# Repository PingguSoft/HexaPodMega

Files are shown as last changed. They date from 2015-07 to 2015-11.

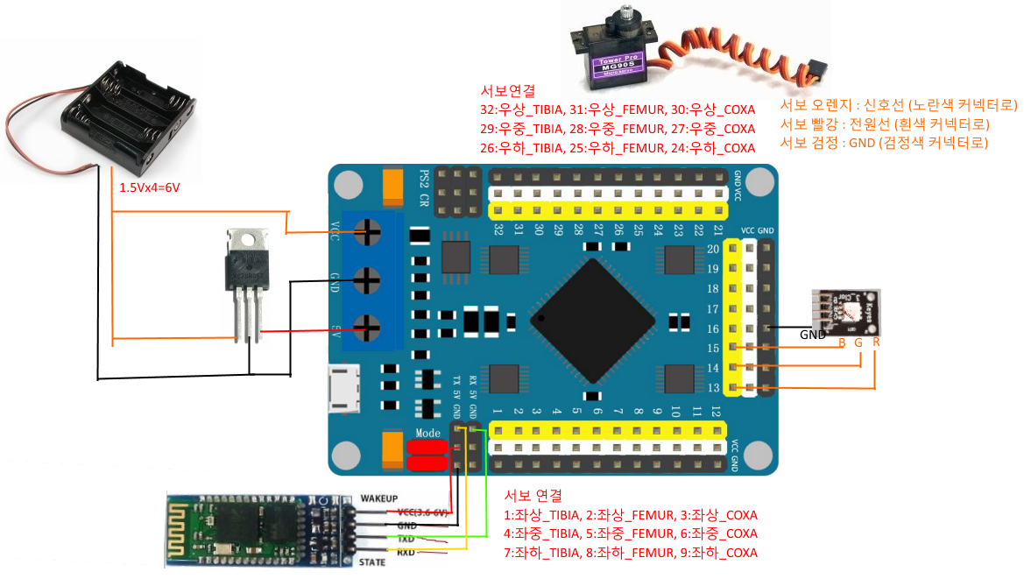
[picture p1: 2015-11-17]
Schematic/ServoController/servo_controller_connection.png

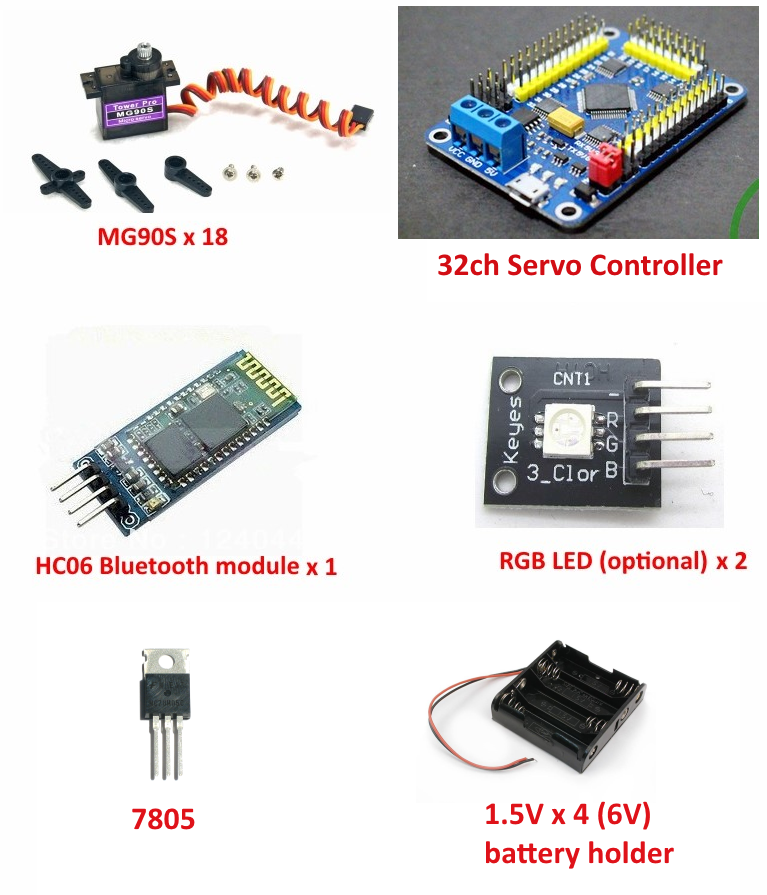
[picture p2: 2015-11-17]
Schematic/ServoController/elec-part2.png

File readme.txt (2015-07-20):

User guide
http://www.lynxmotion.com/images/html/build131.htm
http://www.lynxmotion.com/images/html/build99f.htm
http://www.lynxmotion.com/images/html/build159.htm
http://www.lynxmotion.com/s-6-projects-how-tos.aspx
https://github.com/KurtE/Arduino_Phoenix_Parts
http://learn.trossenrobotics.com/10-interbotix/crawlers/phantomx-hexapod/68-phoenix-code.html

http://www.trossenrobotics.com/
https://code.google.com/p/arbotix/wiki/NukeIntro
http://learn.trossenrobotics.com/10-interbotix/crawlers/phantomx-hexapod/133-phantomx-hexapod-assembly-guide.html

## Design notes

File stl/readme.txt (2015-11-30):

http://www.thingiverse.com/thing:432829
http://www.thingiverse.com/make:130253

Update : modified Phoenix source code added to the files

part needed :
18 mg90s servos
18 623 bearing
1 arduino nano
1 servo controler
1 buzzer
2 led +resistor
1 wireless ps2 controler 
1 rc on-off switch
1 or 2 ubec regulators
diodes.
some siliconed glue to make grip for the foots. (or ninja flex)
many m3 nuts and bolts
and very very little fingers to plug all wire together.
video : https://www.youtube.com/watch?v=Igf-VEXJJVw
sorry for te poor camreman and for the delay on some actions ( i'm trying to remember what all the ps2 button do ;) )
it was made with 123d design.
the code is the kurt's phoenix heavely modified 
Pay attention, in my design all the legs are the same : no left and right design, you must invert rotation by code.

--legs--
epaule_v2 * 6
femur_v2  * 6
tibia-v2  * 6

bottom    * 1
top       * 1
side      * 4

back      * 1  
door      * 1 (bottom door)

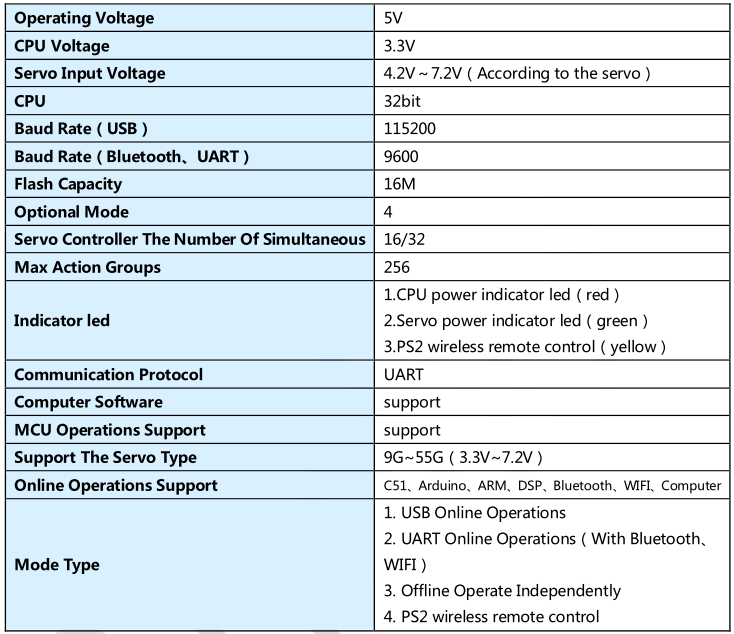
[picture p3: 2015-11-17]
Schematic/ServoController/servo.png

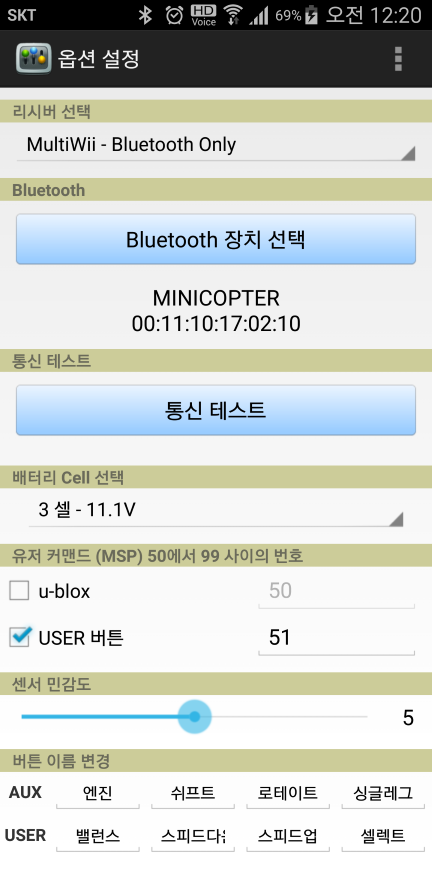
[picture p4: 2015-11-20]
Schematic/ArduinoMega/app1.png

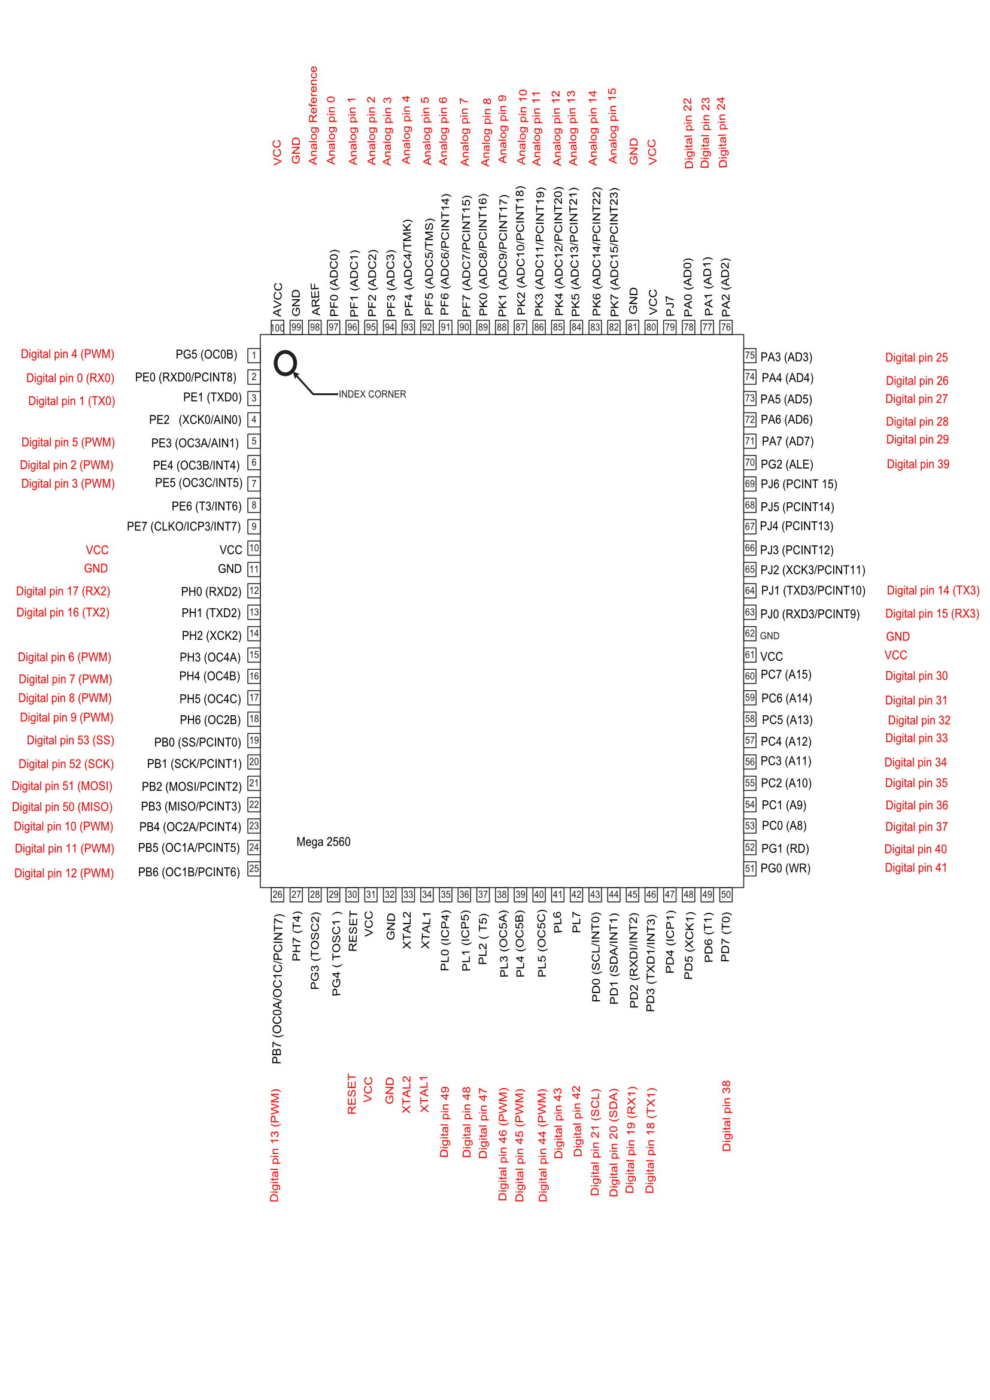
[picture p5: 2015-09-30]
Schematic/ArduinoMega/Pins2560s.png

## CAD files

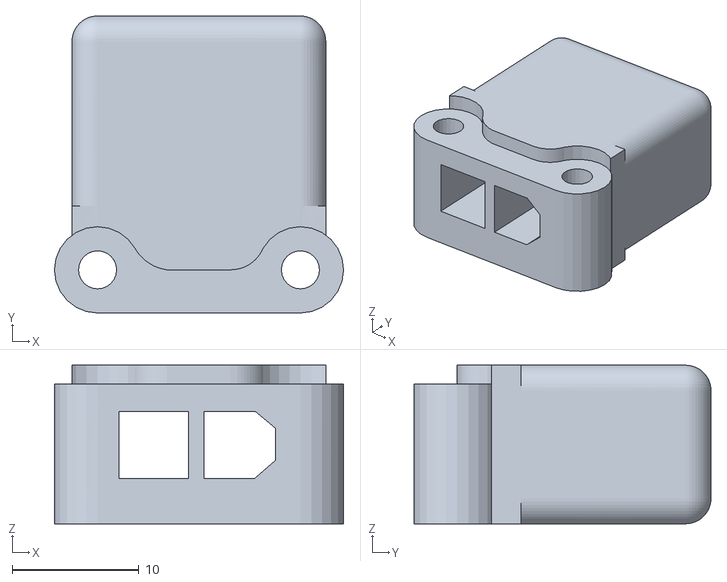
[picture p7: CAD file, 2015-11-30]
stl/BattConnHolder_V2.stl
22.8 x 23.4 x 12.5

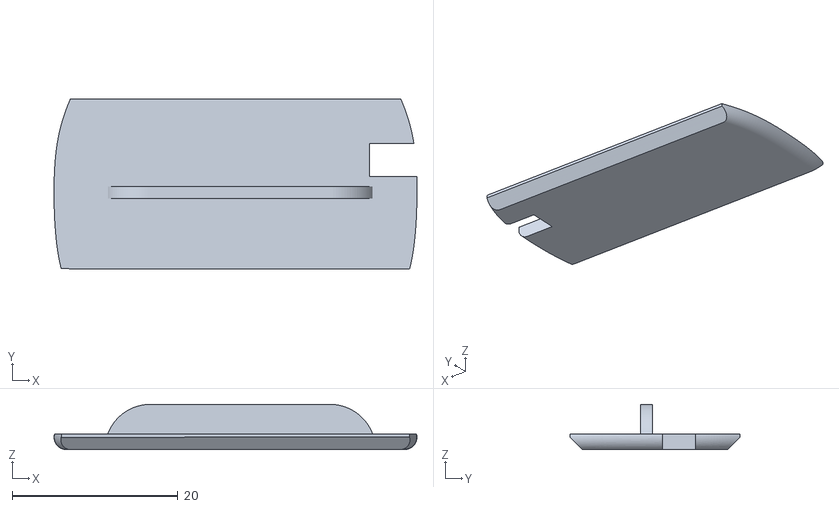
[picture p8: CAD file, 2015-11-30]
stl/updated/head_back.stl
43.9 x 20.6 x 5.47

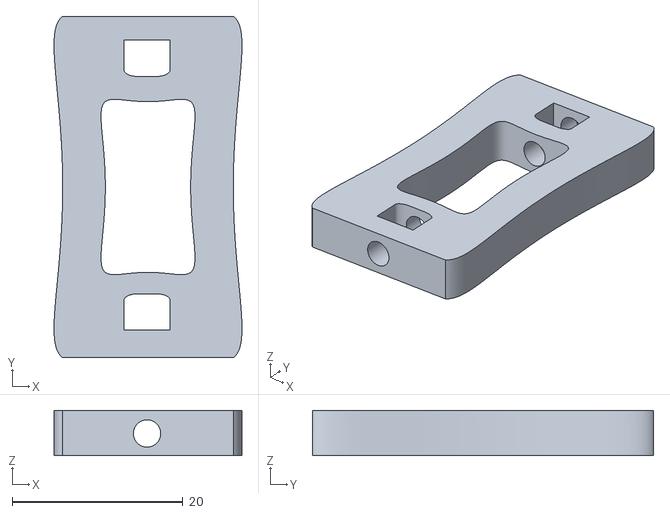
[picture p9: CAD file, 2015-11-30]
stl/hexa_side.stl
22.0 x 40.0 x 5.32

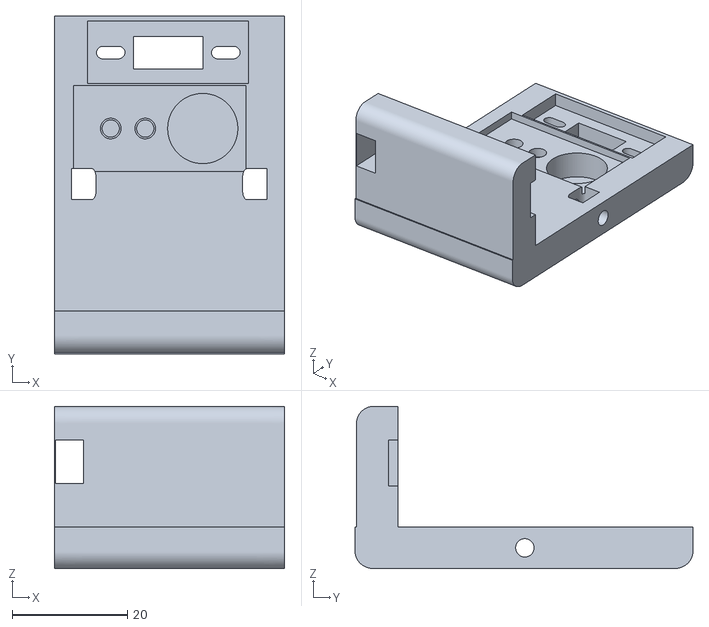
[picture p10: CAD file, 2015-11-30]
stl/hexa_Back.stl
40.0 x 58.8 x 28.2

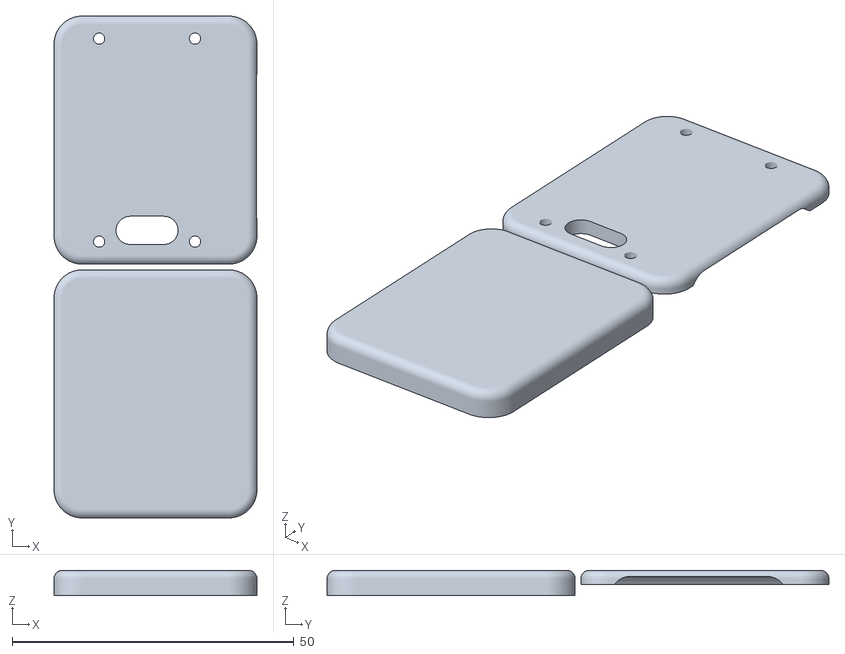
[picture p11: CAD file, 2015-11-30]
stl/ps2_box.stl
36.0 x 89.0 x 4.50

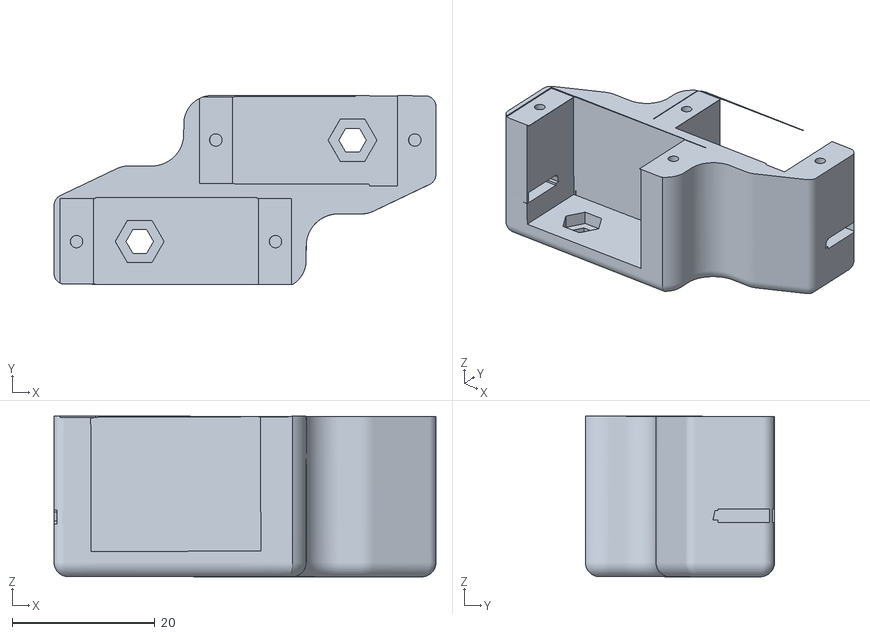
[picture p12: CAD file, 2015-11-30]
stl/femur_v2.stl
53.6 x 26.5 x 22.5

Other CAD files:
stl/hexa_back_xt60.stl

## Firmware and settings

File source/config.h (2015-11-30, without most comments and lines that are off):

#define __CONFIG_H__
#include "common.h"
#if defined(__AVR_ATmega168__) || defined(__AVR_ATmega328P__)
  #define CONFIG_CPU_PROMINI
#elif defined(__AVR_ATmega32U4__) || defined(TEENSY20)
  #define CONFIG_CPU_PROMICRO
#elif defined(__AVR_ATmega1280__) || defined(__AVR_ATmega1281__) || defined(__AVR_ATmega2560__) || defined(__AVR_ATmega2561__)
  #define CONFIG_CPU_MEGA
#endif
#define CONFIG_DOF_PER_LEG      3
#define CONFIG_NUM_LEGS         6
#define CONFIG_TRAVEL_DEAD_ZONE 4
#define CONFIG_ORIGINAL         1
#define CONFIG_NASSPOP_MEGA     2
#define CONFIG_NASSPOP_MINI     3
#define CONFIG_CTRL_TYPE_SERIAL 1
#define CONFIG_CTRL_TYPE_BTCON  2
#define CONFIG_SERVO_SW_PWM     1
#define CONFIG_SERVO_USC        2
#define CONFIG_VBAT_SMOOTH      16
#define CONFIG_VBAT_SCALE       48
#define CONFIG_VBAT_OFFSET      -1   // 0.1v unit
#define CONFIG_VOLT_OFF         111
#define CONFIG_VOLT_ON          115
#define CONFIG_BOARD            CONFIG_NASSPOP_MEGA
#if defined(CONFIG_CPU_MEGA) && !defined(CONFIG_BOARD)
    #error DEFINE CONFIG_BOARD !!!
#elif defined(CONFIG_CPU_PROMINI)
    #define CONFIG_BOARD        CONFIG_NASSPOP_MINI
#endif
#if (CONFIG_BOARD == CONFIG_ORIGINAL)
    #define PIN_ANALOG_VOLT A0
    #define CONFIG_CTRL_SERIAL  Serial
    #define CONFIG_CTRL_BAUD    115200
    #define CONFIG_SERVO        CONFIG_SERVO_SW_PWM
    #define CONFIG_CTRL_TYPE    CONFIG_CTRL_TYPE_BTCON
    #define PIN_STATUS_RED      31
    #define PIN_STATUS_GREEN    30
    #define PIN_STATUS_BLUE     32
    #define PIN_SOUND           37
    #define PIN_RR_COXA         35  //Rear Right leg Hip Horizontal
    #define PIN_RR_FEMUR        36  //Rear Right leg Hip Vertical
    #define PIN_RR_TIBIA        19  //Rear Right leg Knee
    #define PIN_RR_TARS          1  //Tar
    #define PIN_RM_COXA         25  //Middle Right leg Hip Horizontal
    #define PIN_RM_FEMUR        33  //Middle Right leg Hip Vertical
    #define PIN_RM_TIBIA        34  //Middle Right leg Knee
    #define PIN_RM_TARS         1   //Tar
    #define PIN_RF_COXA         22  //Front Right leg Hip Horizontal
    #define PIN_RF_FEMUR        23  //Front Right leg Hip Vertical
    #define PIN_RF_TIBIA        24  //Front Right leg Knee
    #define PIN_RF_TARS         1   //Tar
    #define PIN_LR_COXA         9  //Rear Left leg Hip Horizontal
    #define PIN_LR_FEMUR        10  //Rear Left leg Hip Vertical
    #define PIN_LR_TIBIA        11  //Rear Left leg Knee
    #define PIN_LR_TARS         1  //Tar
    #define PIN_LM_COXA         6  //Middle Left leg Hip Horizontal
    #define PIN_LM_FEMUR        7  //Middle Left leg Hip Vertical
    #define PIN_LM_TIBIA        8  //Middle Left leg Knee
    #define PIN_LM_TARS         1  //Tar = Not working...
    #define PIN_LF_COXA         2  //Front Left leg Hip Horizontal
    #define PIN_LF_FEMUR        3  //Front Left leg Hip Vertical
    #define PIN_LF_TIBIA        5  //Front Left leg Knee
    #define PIN_LF_TARS         1  //Tar
#elif (CONFIG_BOARD == CONFIG_NASSPOP_MEGA)
    #define CONFIG_DBG_SERIAL   Serial
    #define CONFIG_DEBUG_BAUD   115200
    #define CONFIG_CTRL_SERIAL  Serial1
    #define CONFIG_CTRL_BAUD    115200
    #define CONFIG_SERVO        CONFIG_SERVO_SW_PWM
    #define CONFIG_CTRL_TYPE    CONFIG_CTRL_TYPE_BTCON
    #define PIN_STATUS_RED      A7
    #define PIN_STATUS_GREEN    A6
    #define PIN_STATUS_BLUE     A5
    #define PIN_SOUND           A14
    #define PIN_RR_COXA         44  //Rear Right leg Hip Horizontal
    #define PIN_RR_FEMUR        45  //Rear Right leg Hip Vertical
    #define PIN_RR_TIBIA        46  //Rear Right leg Knee
    #define PIN_RR_TARS          1  //Tar
    #define PIN_RM_COXA         35  //Middle Right leg Hip Horizontal
    #define PIN_RM_FEMUR        33  //Middle Right leg Hip Vertical
    #define PIN_RM_TIBIA        36  //Middle Right leg Knee
    #define PIN_RM_TARS          1  //Tar
    #define PIN_RF_COXA         A15 //Front Right leg Hip Horizontal
    #define PIN_RF_FEMUR        32  //Front Right leg Hip Vertical
    #define PIN_RF_TIBIA        34  //Front Right leg Knee
    #define PIN_RF_TARS          1  //Tar
    #define PIN_LR_COXA         9  //Rear Left leg Hip Horizontal
    #define PIN_LR_FEMUR        10  //Rear Left leg Hip Vertical
    #define PIN_LR_TIBIA        11  //Rear Left leg Knee
    #define PIN_LR_TARS         1  //Tar
    #define PIN_LM_COXA         6  //Middle Left leg Hip Horizontal
    #define PIN_LM_FEMUR        7  //Middle Left leg Hip Vertical
    #define PIN_LM_TIBIA        8  //Middle Left leg Knee
    #define PIN_LM_TARS         1  //Tar = Not working...
    #define PIN_LF_COXA         2  //Front Left leg Hip Horizontal
    #define PIN_LF_FEMUR        3  //Front Left leg Hip Vertical
    #define PIN_LF_TIBIA        5  //Front Left leg Knee
    #define PIN_LF_TARS         1  //Tar
#elif (CONFIG_BOARD == CONFIG_NASSPOP_MINI)
    #define CONFIG_SERVO            CONFIG_SERVO_USC
    #define CONFIG_SERVO_MARGIN     200
    #define CONFIG_SERVO_USC_TX     12
    #define CONFIG_SERVO_USC_RX     11
    #define CONFIG_SERVO_USC_BAUD   9600
    #ifdef CONFIG_DBG_SERIAL
        #define CONFIG_CTRL_SERIAL      Serial
        #define CONFIG_CTRL_BAUD        115200
        #define CONFIG_CTRL_TYPE        CONFIG_CTRL_TYPE_SERIAL
    #else
        #define CONFIG_CTRL_SERIAL      Serial
        #define CONFIG_CTRL_BAUD        115200
        #define CONFIG_CTRL_TYPE        CONFIG_CTRL_TYPE_BTCON
    #endif
    #if !defined(CONFIG_SERVO_USC_TX) && (CONFIG_SERVO_USC_BAUD != CONFIG_CTRL_BAUD)
        #error SHARED UART BAUD IS NOT SAME !!!
    #endif
    #define PIN_STATUS_RED       6
    #define PIN_STATUS_GREEN     3
    #define PIN_STATUS_BLUE      5
    #define PIN_SOUND            2
    #define PIN_RR_COXA         24  //Rear Right leg Hip Horizontal
    #define PIN_RR_FEMUR        25  //Rear Right leg Hip Vertical
    #define PIN_RR_TIBIA        26  //Rear Right leg Knee
    #define PIN_RR_TARS          0  //Tar
    #define PIN_RM_COXA         27  //Middle Right leg Hip Horizontal
    #define PIN_RM_FEMUR        28  //Middle Right leg Hip Vertical
    #define PIN_RM_TIBIA        29  //Middle Right leg Knee
    #define PIN_RM_TARS          0  //Tar
    #define PIN_RF_COXA         30 //Front Right leg Hip Horizontal
    #define PIN_RF_FEMUR        31  //Front Right leg Hip Vertical
    #define PIN_RF_TIBIA        32  //Front Right leg Knee
    #define PIN_RF_TARS          0  //Tar
    #define PIN_LR_COXA         9  //Rear Left leg Hip Horizontal
    #define PIN_LR_FEMUR        8  //Rear Left leg Hip Vertical
    #define PIN_LR_TIBIA        7  //Rear Left leg Knee
    #define PIN_LR_TARS         0  //Tar
    #define PIN_LM_COXA         6  //Middle Left leg Hip Horizontal
    #define PIN_LM_FEMUR        5  //Middle Left leg Hip Vertical
    #define PIN_LM_TIBIA        4  //Middle Left leg Knee
    #define PIN_LM_TARS         0  //Tar = Not working...
    #define PIN_LF_COXA         3  //Front Left leg Hip Horizontal
    #define PIN_LF_FEMUR        2  //Front Left leg Hip Vertical
    #define PIN_LF_TIBIA        1  //Front Left leg Knee
    #define PIN_LF_TARS         0  //Tar
#endif
#if  (CONFIG_SERVO == CONFIG_SERVO_USC)
    #define CONFIG_SERVO_MARGIN 200
#else
    #define CONFIG_SERVO_MARGIN 0
#endif
#define COXA_MIN_ANG    -800
#define COXA_MAX_ANG     800
#define FEMUR_MIN_ANG   -800
#define FEMUR_MAX_ANG    800
#define TIBIA_MIN_ANG   -800
#define TIBIA_MAX_ANG    800
#define cRRCoxaMin1	    COXA_MIN_ANG	//Mechanical limits of the Right Rear Leg, decimals = 1
#define cRRCoxaMax1	    COXA_MAX_ANG
#define cRRFemurMin1	FEMUR_MIN_ANG
#define cRRFemurMax1	FEMUR_MAX_ANG
#define cRRTibiaMin1	TIBIA_MIN_ANG
#define cRRTibiaMax1	TIBIA_MAX_ANG
#define cRMCoxaMin1	    COXA_MIN_ANG	//Mechanical limits of the Right Middle Leg, decimals = 1
#define cRMCoxaMax1	    COXA_MAX_ANG
#define cRMFemurMin1	FEMUR_MIN_ANG
#define cRMFemurMax1	FEMUR_MAX_ANG
#define cRMTibiaMin1	TIBIA_MIN_ANG
#define cRMTibiaMax1	TIBIA_MAX_ANG
#define cRFCoxaMin1	    COXA_MIN_ANG	//Mechanical limits of the Right Front Leg, decimals = 1
#define cRFCoxaMax1	    COXA_MAX_ANG
#define cRFFemurMin1	FEMUR_MIN_ANG
#define cRFFemurMax1	FEMUR_MAX_ANG
#define cRFTibiaMin1	TIBIA_MIN_ANG
#define cRFTibiaMax1	TIBIA_MAX_ANG
#define cLRCoxaMin1	    COXA_MIN_ANG	//Mechanical limits of the Left Rear Leg, decimals = 1
#define cLRCoxaMax1	    COXA_MAX_ANG
#define cLRFemurMin1	FEMUR_MIN_ANG
#define cLRFemurMax1	FEMUR_MAX_ANG
#define cLRTibiaMin1	TIBIA_MIN_ANG
#define cLRTibiaMax1	TIBIA_MAX_ANG
#define cLMCoxaMin1	    COXA_MIN_ANG	//Mechanical limits of the Left Middle Leg, decimals = 1
#define cLMCoxaMax1	    COXA_MAX_ANG
#define cLMFemurMin1	FEMUR_MIN_ANG
#define cLMFemurMax1	FEMUR_MAX_ANG
#define cLMTibiaMin1	TIBIA_MIN_ANG
#define cLMTibiaMax1	TIBIA_MAX_ANG
#define cLFCoxaMin1	    COXA_MIN_ANG	//Mechanical limits of the Left Front Leg, decimals = 1
#define cLFCoxaMax1	    COXA_MAX_ANG
#define cLFFemurMin1	FEMUR_MIN_ANG
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

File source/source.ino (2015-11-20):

//=============================================================================
//Project Lynxmotion Phoenix
//Description: Phoenix software
//Software version: V2.0
//Date: 29-10-2009
//Programmer: Jeroen Janssen [aka Xan]
//         Kurt Eckhardt(KurtE) converted to C and Arduino
//   KÃ¥re Halvorsen aka Zenta - Makes everything work correctly!
//
// This version of the Phoenix code was ported over to the Arduino Environement
// and is specifically configured for the Lynxmotion BotBoarduino
//
// Date : 12-07-2015
// Programmer : PingguSoft (pinggusoft@gmail.com)
//              Code rework for smartphone control and readability
//              Android App : BTCon4Drone
//               https://play.google.com/store/apps/details?id=com.pinggusoft.btcon
//=============================================================================

#if defined(__AVR_ATmega1280__) || defined(__AVR_ATmega1281__) || defined(__AVR_ATmega2560__) || defined(__AVR_ATmega2561__)
    #define SERIAL_RX_BUFFER_SIZE 256
    #define SERIAL_TX_BUFFER_SIZE 256
#endif

#define DEFINE_HEX_GLOBALS
#if ARDUINO > 99
#include <Arduino.h>
#endif
#include <Wire.h>
#include <EEPROM.h>
#include <SoftwareSerial.h>

#include "common.h"
#include "ServoEx.h"
#include "config.h"
#include "PhoenixCore.h"
#include "PhoenixInput.h"
#include "PhoenixInputSerial.h"
#include "PhoenixInputBTCon.h"
#include "PhoenixServo.h"
#include "PhoenixServoSW.h"
#include "PhoenixServoUSC.h"

enum {
    MODE_WALK = 0,
    MODE_TRANSLATE,
    MODE_ROTATE,
    MODE_SINGLE_LEG
};

PhoenixCore  *core;
PhoenixInput *input;
CTRL_STATE   ctrlState;

u8        mColor;
s16       mBodyYOffset;
u16       mErrorCnt;
s16       mBodyYShift;
u8        mModeControl;
bool      mBoolDoubleHeight;
bool      mBoolDblTravel;
bool      mBoolWalkMode2;



int freeRam() {
    extern int __heap_start, *__brkval;
    int v;
    return (int) &v - (__brkval == 0 ? (int) &__heap_start : (int) __brkval);
}


#if (CONFIG_CTRL_TYPE == CONFIG_CTRL_TYPE_BTCON)
u8 scale = 30;
s8 inputCallback(u8 cmd, u8 *data, u8 size, u8 *res)
{
    s8 ret = -1;

    switch (cmd) {
        case PhoenixInputBTCon::MSP_ANALOG:
            if (core) {
                u8 *ptr = (u8*)res;

                *ptr = core->getBattLevel(scale);
                *(ptr + 3) = core->getBattLevel();
                ret = 7;
            }
            break;

        case PhoenixInputBTCon::MSP_SET_MISC:
            scale = *(data + 18);
            ret = 0;
            break;
    }
    return ret;
}
#endif

enum {
    COLOR_BLACK  = 0,
    COLOR_RED    = 1,
    COLOR_GREEN  = 2,
    COLOR_YELLOW = 3,
    COLOR_BLUE   = 4,
    COLOR_PURPLE = 5,
    COLOR_CYAN   = 6,
    COLOR_WHITE  = 7
};

void showLED(u8 color)
{
    //printf(F("COLOR : %d\n"), color);
    digitalWrite(PIN_STATUS_RED,   color & 0x01);
    digitalWrite(PIN_STATUS_GREEN, color & 0x02);
    digitalWrite(PIN_STATUS_BLUE,  color & 0x04);
}

void setup()
{
    pinMode(PIN_STATUS_RED,   OUTPUT);
    pinMode(PIN_STATUS_GREEN, OUTPUT);
    pinMode(PIN_STATUS_BLUE,  OUTPUT);
    pinMode(PIN_SOUND, OUTPUT);

    mColor       = 0;
    mBodyYOffset = 0;
    mBodyYShift  = 0;
    mErrorCnt    = 0;

    mModeControl      = MODE_WALK;
    mBoolDoubleHeight = FALSE;
    mBoolDblTravel    = FALSE;
    mBoolWalkMode2    = FALSE;

#ifdef CONFIG_DBG_SERIAL
    CONFIG_DBG_SERIAL.begin(CONFIG_DEBUG_BAUD);
#endif


#if (CONFIG_CTRL_TYPE == CONFIG_CTRL_TYPE_SERIAL)
    input = new PhoenixInputSerial();
	input->init(NULL);

#elif (CONFIG_CTRL_TYPE == CONFIG_CTRL_TYPE_BTCON)
    CONFIG_CTRL_SERIAL.begin(CONFIG_CTRL_BAUD);
    input = new PhoenixInputBTCon(&CONFIG_CTRL_SERIAL);
	input->init(inputCallback);

#else
    #error No Controller !!
#endif


    PhoenixServo    *servo;
#if (CONFIG_SERVO == CONFIG_SERVO_SW_PWM)
    servo = new PhoenixServoSW();

#elif (CONFIG_SERVO == CONFIG_SERVO_USC)
    #if (CONFIG_BOARD == CONFIG_NASSPOP_MINI) && defined(CONFIG_SERVO_USC_TX)
        servo = new PhoenixServoUSC();
    #else
        servo = new PhoenixServoUSC(&CONFIG_CTRL_SERIAL);
    #endif

#endif

    core = new PhoenixCore(servo, &ctrlState);
	core->init();

    printf(F("FREE RAM : %d\n"), freeRam());
}

#define BUTTON_PRESSED(stat, mask) (stat & (mask))

void turnOff(void)
{
    mBodyYOffset = 0;
    mBodyYShift  = 0;
    core->initCtrl();
    Utils::sound(400, 0, 0, 100, 300);
    printf(F("OFF\n"));
}

void loop()
{
    u32  dwButton;
    u8   lx, ly, rx, ry;
    u8   ret;
    bool fAdjustLegPositions = FALSE;

	dwButton = input->get(&lx, &ly, &rx, &ry);

    if (!dwButton)
        goto loop_exit;

    if (BUTTON_PRESSED(dwButton, INPUT_TOGGLE_ON_OFF)) {
    	if (ctrlState.fHexOn) {
            turnOff();
            mColor = 0;
        } else {
            ctrlState.fHexOn = TRUE;
            printf(F("ON\n"));
            Utils::sound(200, 200, 0, 100, 300);
        }
        fAdjustLegPositions = TRUE;
    }

    if (!ctrlState.fHexOn)
        goto loop_exit;

    // Switch between Walk method 1 && Walk method 2
    if (BUTTON_PRESSED(dwButton, INPUT_TOGGLE_WALK)) { // R3 Button Test
        Utils::sound(100, 100, 100, 50, 300);
        mBoolWalkMode2 = !mBoolWalkMode2;
    }

    if (BUTTON_PRESSED(dwButton, INPUT_TOGGLE_SHIFT)) {
        Utils::sound(100, 0, 0, 50, 300);
        if (mModeControl != MODE_TRANSLATE )
            mModeControl = MODE_TRANSLATE;
        else
            mModeControl = MODE_WALK;
        printf(F("MODE:%d\n"), mModeControl);
    }

    if (BUTTON_PRESSED(dwButton, INPUT_TOGGLE_ROTATE)) {
        Utils::sound(300, 0, 0, 50, 300);
        if (mModeControl != MODE_ROTATE)
            mModeControl = MODE_ROTATE;
        else
            mModeControl = MODE_WALK;
        printf(F("MODE:%d\n"), mModeControl);
    }

    if (BUTTON_PRESSED(dwButton, INPUT_TOGGLE_SINGLE_LEG)) {
        if (abs(ctrlState.c3dTravelLen.x) < CONFIG_TRAVEL_DEAD_ZONE && abs(ctrlState.c3dTravelLen.z) < CONFIG_TRAVEL_DEAD_ZONE &&
            abs(ctrlState.c3dTravelLen.y * 2) < CONFIG_TRAVEL_DEAD_ZONE )   {
            Utils::sound(300, 0, 0, 50, 300);

            if (mModeControl != MODE_SINGLE_LEG) {
                mModeControl = MODE_SINGLE_LEG;

            if (ctrlState.bSingleLegCurSel == 255)
                ctrlState.bSingleLegCurSel = PhoenixCore::IDX_RF;
            } else {
                mModeControl = MODE_WALK;
                ctrlState.bSingleLegCurSel = 255;
            }
        }
        printf(F("MODE:%d\n"), mModeControl);
    }

    if (BUTTON_PRESSED(dwButton, INPUT_TOGGLE_BALANCE)) {
        ctrlState.fBalanceMode = !ctrlState.fBalanceMode;
        if (ctrlState.fBalanceMode) {
            Utils::sound(30, 30, 0, 50, 300);
        } else {
            Utils::sound(300, 0, 0, 50, 300);
        }
    }

    if (BUTTON_PRESSED(dwButton, INPUT_TOGGLE_BODY_HEIGHT)) {
        if (mBodyYOffset > 0)
            mBodyYOffset = 0;
        else
            mBodyYOffset = 35;
        fAdjustLegPositions = TRUE;
    }

    if (input->getBodyHeight() & INPUT_HEIGHT_SUPPORTED) {
        mBodyYOffset = input->getBodyHeight() & INPUT_HEIGHT_MASK;
        if (mBodyYOffset > MAX_BODY_Y)
                mBodyYOffset = MAX_BODY_Y;
        fAdjustLegPositions = TRUE;
    } else {
        if (BUTTON_PRESSED(dwButton, INPUT_BODY_UP)) {
            mBodyYOffset += 10;
            if (mBodyYOffset > MAX_BODY_Y)
                mBodyYOffset = MAX_BODY_Y;
            fAdjustLegPositions = TRUE;
        }

        if (BUTTON_PRESSED(dwButton, INPUT_BODY_DOWN) && mBodyYOffset) {
            if (mBodyYOffset > 10)
                mBodyYOffset -= 10;
            else
                mBodyYOffset = 0;
            fAdjustLegPositions = TRUE;
        }
    }

    if (BUTTON_PRESSED(dwButton, INPUT_SPEED_UP)) {
        if (ctrlState.wSpeedControl > 0) {
            ctrlState.wSpeedControl = ctrlState.wSpeedControl - 50;
            Utils::sound(300, 0, 0, 50, 300);
        }
    }

    if (BUTTON_PRESSED(dwButton, INPUT_SPEED_DOWN)) {
        if (ctrlState.wSpeedControl < 2000 ) {
            ctrlState.wSpeedControl = ctrlState.wSpeedControl + 50;
            Utils::sound(300, 0, 0, 50, 300);
        }
    }

    if (mModeControl == MODE_WALK) {
        //Switch gaits
        if (BUTTON_PRESSED(dwButton, INPUT_OPT_SEL)) {
            printf(F("x:%d, y:%d, z:%d\n"), ctrlState.c3dTravelLen.x, ctrlState.c3dTravelLen.y, ctrlState.c3dTravelLen.z);
            if (abs(ctrlState.c3dTravelLen.x) < CONFIG_TRAVEL_DEAD_ZONE &&
                abs(ctrlState.c3dTravelLen.z) < CONFIG_TRAVEL_DEAD_ZONE &&
                abs(ctrlState.c3dTravelLen.y*2) < CONFIG_TRAVEL_DEAD_ZONE) {
                ctrlState.bGaitType = ctrlState.bGaitType + 1;    // Go to the next gait...
                if (ctrlState.bGaitType < NUM_GAITS) {            // Make sure we did not exceed number of gaits...
                    Utils::sound(300, 0, 0, 50, 300);
                } else {
                    Utils::sound(100, 100, 0, 50, 300);
                    ctrlState.bGaitType = 0;
                }
                core->selectGait(ctrlState.bGaitType);
                printf(F("GAIT:%d\n"), ctrlState.bGaitType);
            } else {
                printf(F("GAIT can not be changed:%d\n"), ctrlState.bGaitType);
            }
        }

        // Double leg lift height
        if (BUTTON_PRESSED(dwButton, INPUT_OPT_R1)) {
            Utils::sound(300, 0, 0, 50, 300);
            mBoolDoubleHeight = !mBoolDoubleHeight;
            if (mBoolDoubleHeight)
                ctrlState.sLegLiftHeight = 80;
            else
                ctrlState.sLegLiftHeight = 50;
        }

        // Double Travel Length
        if (BUTTON_PRESSED(dwButton, INPUT_OPT_R2)) {
            Utils::sound(300, 0, 0, 50, 300);
            mBoolDblTravel = !mBoolDblTravel;
        }

        if (mBoolWalkMode2)
            ctrlState.c3dTravelLen.z = (ry - 128); //Right Stick Up/Down
        else {
            ctrlState.c3dTravelLen.x = -(lx - 128);
            ctrlState.c3dTravelLen.z = (ly - 128);
        }

        if (!mBoolDblTravel) {
            ctrlState.c3dTravelLen.x = ctrlState.c3dTravelLen.x / 2;
            ctrlState.c3dTravelLen.z = ctrlState.c3dTravelLen.z / 2;
        }

        ctrlState.c3dTravelLen.y = -(rx - 128)/4; //Right Stick Left/Right
    }

    if (ctrlState.fHexOn)
        mColor = 1 + mModeControl + (mBoolDblTravel ? 4 : 0);

    //[Translate functions]
    mBodyYShift = 0;
    if (mModeControl == MODE_TRANSLATE) {
        ctrlState.c3dBodyPos.x = (ly - 128)/2;
        ctrlState.c3dBodyPos.z = -(ly - 128)/3;
        ctrlState.c3dBodyRot.y = (rx - 128)*2;
        mBodyYShift = (-(ry - 128)/2);
    } else if (mModeControl == MODE_ROTATE) {
        ctrlState.c3dBodyRot.x = (ly - 128);
        ctrlState.c3dBodyRot.y = (rx - 128)*2;
        ctrlState.c3dBodyRot.z = (lx - 128);
        mBodyYShift = (-(ry - 128)/2);
    } else if (mModeControl == MODE_SINGLE_LEG) {
        if (BUTTON_PRESSED(dwButton, INPUT_OPT_SEL)) { // Select Button Test
            Utils::sound(300, 0, 0, 50, 300);
            if (ctrlState.bSingleLegCurSel < 5)
                ctrlState.bSingleLegCurSel = ctrlState.bSingleLegCurSel + 1;
            else
                ctrlState.bSingleLegCurSel = 0;
        }
        ctrlState.c3dSingleLeg.x = (lx - 128) / 2;     // Left Stick Right/Left
        ctrlState.c3dSingleLeg.y = (ry - 128) / 10;    // Right Stick Up/Down
        ctrlState.c3dSingleLeg.z = (ly - 128) / 2;     // Left Stick Up/Down

        // Hold single leg in place
        if (BUTTON_PRESSED(dwButton, INPUT_OPT_R2)) {
            Utils::sound(300, 0, 0, 50, 300);
            ctrlState.fSingleLegHold = !ctrlState.fSingleLegHold;
        }
    }

    ctrlState.bInputTimeDelay = 128 - max( max(abs(lx - 128), abs(ly - 128)),
                                             abs(rx - 128));
    ctrlState.c3dBodyPos.y = min(max(mBodyYOffset + mBodyYShift,  0), MAX_BODY_Y);

loop_exit:
    if (fAdjustLegPositions)
        core->adjustLegPosToBodyHeight();

    showLED(mColor);

    ret = core->loop();
#if 0
    if (ctrlState.fHexOn && (ret & PhoenixCore::STATUS_BATT_FAIL)) {
        turnOff();
        ctrlState.c3dBodyPos.y = 0;
        core->adjustLegPosToBodyHeight();
        core->loop();
    } else if (ret & PhoenixCore::STATUS_BATT_WARN) {
        Utils::sound(50, 50, 50, 50, 300);
    }
#endif
    Utils::handleSound();

    ctrlState.fHexOnOld = ctrlState.fHexOn;
}

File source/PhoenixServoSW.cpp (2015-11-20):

/*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
 This program is distributed in the hope that it will be useful,
 but WITHOUT ANY WARRANTY; without even the implied warranty of
 MERCHANTABILITY or FITNESS FOR A PARTICULAR PURPOSE.  See the
 GNU General Public License for more details.
 see <http://www.gnu.org/licenses/>
*/


#include <EEPROM.h>
#include "PhoenixServoSW.h"

static const u8 TBL_COXA_PIN[] PROGMEM = {
    PIN_RR_COXA,  PIN_RM_COXA,  PIN_RF_COXA,  PIN_LR_COXA,  PIN_LM_COXA,  PIN_LF_COXA
};

static const u8 TBL_FEMUR_PIN[] PROGMEM = {
    PIN_RR_FEMUR, PIN_RM_FEMUR, PIN_RF_FEMUR, PIN_LR_FEMUR, PIN_LM_FEMUR, PIN_LF_FEMUR
};

static const u8 TBL_TIBIA_PIN[] PROGMEM = {
    PIN_RR_TIBIA, PIN_RM_TIBIA, PIN_RF_TIBIA, PIN_LR_TIBIA, PIN_LM_TIBIA, PIN_LF_TIBIA
};

#if (CONFIG_DOF_PER_LEG == 4)
static const u8 TBL_TARS_PIN[] PROGMEM = {
    PIN_RR_TARS, PIN_RM_TARS, PIN_RF_TARS, PIN_LR_TARS, PIN_LM_TARS, PIN_LF_TARS
};
#endif

static const s16 TBL_LEGS_OFFSET[] PROGMEM = {
    0, -150,  -70,
    0, -115,  160,
    0,  -55,   80,
    0,   45,    0,
    0, -115,  165,
    0, -135,   60,
};

PhoenixServoSW::PhoenixServoSW(void)
{
}

//-----------------------------------------------------------------------------
// Helper function to load the servo offsets from the EEPROM
//-----------------------------------------------------------------------------
void PhoenixServoSW::loadServosConfig(void)
{
    u8    *pb = (u8*)&mServoOffsets;
    u8    bChkSum = 0;
    int   i;

    memset(mServoOffsets, 0, sizeof(mServoOffsets));

    if (EEPROM.read(0) == CONFIG_NUM_LEGS * CONFIG_DOF_PER_LEG) {
        printf(F("Load from EEPROM !!\n"));
        for (i=0; i < sizeof(mServoOffsets); i++) {
            *pb = EEPROM.read(i+2);
            bChkSum += *pb++;
        }
        if (bChkSum == EEPROM.read(1)) {
            printf(F("Offset checksum is okay !!\n"));
            return;
        }
    }

    printf(F("Load default !!\n"));
    for (i = 0; i < CONFIG_NUM_LEGS * CONFIG_DOF_PER_LEG; i++) {
        mServoOffsets[i] = (s16)pgm_read_word(&TBL_LEGS_OFFSET[i]);
    }
}


//-----------------------------------------------------------------------------
// init
//-----------------------------------------------------------------------------
void PhoenixServoSW::init(void)
{
    printf(F("%s\n"), __PRETTY_FUNCTION__);

    mBoolServosAttached = FALSE;
    loadServosConfig();

    mVoltSum = 0;
    mVoltIdx = 0;
    memset(mVoltBuf, 0, sizeof(mVoltBuf));

    for (u8 i = 0; i < CONFIG_VBAT_SMOOTH; i++)
        getBattVolt();
}

//-----------------------------------------------------------------------------
// getBattVolt
//-----------------------------------------------------------------------------
u8 PhoenixServoSW::getBattVolt(void)
{
    u16 v;
#ifdef PIN_ANALOG_VOLT
    v = analogRead(PIN_ANALOG_VOLT);

    mVoltSum += v;
    mVoltSum -= mVoltBuf[mVoltIdx];
    mVoltBuf[mVoltIdx++] = v;
    mVoltIdx %= CONFIG_VBAT_SMOOTH;

    u8 t;

    #if CONFIG_VBAT_SMOOTH == 16
        t = mVoltSum / CONFIG_VBAT_SCALE + CONFIG_VBAT_OFFSET;
    #elif CONFIG_VBAT_SMOOTH < 16
        t = (mVoltSum * (16 / CONFIG_VBAT_SMOOTH)) / CONFIG_VBAT_SCALE + CONFIG_VBAT_OFFSET;
    #else
        t = ((mVoltSum / CONFIG_VBAT_SMOOTH) * 16) / CONFIG_VBAT_SCALE + CONFIG_VBAT_OFFSET;
    #endif

    printf(F("analog:%d voltsum:%d, v:%d\n"), v, mVoltSum, t);

    return t;
#else
    return CONFIG_VOLT_ON;
#endif
}

//-----------------------------------------------------------------------------
// attachServos
//-----------------------------------------------------------------------------
void PhoenixServoSW::attachServos(void)
{
    u8 tot = 0;

    if (!mBoolServosAttached) {
        for (u8 j = 0; j < CONFIG_NUM_LEGS; j++) {
            mServoLegs[tot++].attach(pgm_read_byte(&TBL_COXA_PIN[j]));
            mServoLegs[tot++].attach(pgm_read_byte(&TBL_FEMUR_PIN[j]));
            mServoLegs[tot++].attach(pgm_read_byte(&TBL_TIBIA_PIN[j]));
#if (CONFIG_DOF_PER_LEG == 4)
            mServoLegs[tot++].attach(pgm_read_byte(&TBL_TARS_PIN[j]));
#endif
        }
        mBoolServosAttached = TRUE;
    }
}


//-----------------------------------------------------------------------------
// start
//-----------------------------------------------------------------------------
void PhoenixServoSW::start(void)
{
    attachServos();
    mSGM.start();   // tell the group move system we are starting a new move
}

//-----------------------------------------------------------------------------
// write
//-----------------------------------------------------------------------------
#define PWM_DIV       991  //old 1059;
#define PF_CONST      592  //old 650 ; 900*(1000/PWM_DIV)+PF_CONST must always be 1500

// A PWM/deg factor of 10,09 give PWM_DIV = 991 and PF_CONST = 592
// For a modified 5645 (to 180 deg travel): PWM_DIV = 1500 and PF_CONST = 900.
#if (CONFIG_DOF_PER_LEG == 4)
void PhoenixServoSW::write(u8 leg, s16 sCoxaAngle1, s16 sFemurAngle1, s16 sTibiaAngle1, s16 sTarsAngle1)
#else
void PhoenixServoSW::write(u8 leg, s16 sCoxaAngle1, s16 sFemurAngle1, s16 sTibiaAngle1)
#endif
{
    u16    wCoxaSSCV;
    u16    wFemurSSCV;
    u16    wTibiaSSCV;
#if (CONFIG_DOF_PER_LEG == 4)
    u16    wTarsSSCV;
#endif

    if (leg < 3) {
        wCoxaSSCV  = ((long)(sCoxaAngle1   + 900)) * 1000 / PWM_DIV + PF_CONST;
        wFemurSSCV = ((long)(-sFemurAngle1 + 900)  * 1000 / PWM_DIV + PF_CONST);
        wTibiaSSCV = ((long)(-sTibiaAngle1 + 900)) * 1000 / PWM_DIV + PF_CONST;
#if (CONFIG_DOF_PER_LEG == 4)
        wTarsSSCV  = ((long)(-sTarsAngle1  + 900)) * 1000 / PWM_DIV + PF_CONST;
#endif
    } else {
        wCoxaSSCV  = ((long)(-sCoxaAngle1  + 900)) * 1000 / PWM_DIV + PF_CONST;
        wFemurSSCV = ((long)((long)(-sFemurAngle1 + 900)) * 1000 / PWM_DIV + PF_CONST);
        wTibiaSSCV = ((long)(-sTibiaAngle1 + 900)) * 1000 / PWM_DIV + PF_CONST;
#if (CONFIG_DOF_PER_LEG == 4)
        wTarsSSCV  = ((long)(sTarsAngle1 + 900)) * 1000 / PWM_DIV + PF_CONST;
#endif
    }

    u8 i = leg * CONFIG_DOF_PER_LEG;
    mServoLegs[i].writeMicroseconds(wCoxaSSCV + mServoOffsets[i]);
    i++;
    mServoLegs[i].writeMicroseconds(wFemurSSCV + mServoOffsets[i]);
    i++;
    mServoLegs[i].writeMicroseconds(wTibiaSSCV + mServoOffsets[i]);
#if (CONFIG_DOF_PER_LEG == 4)
    i++;
    mServoLegs[i].writeMicroseconds(wTarsSSCV + mServoOffsets[i]);
#endif
}

//-----------------------------------------------------------------------------
// commit
//-----------------------------------------------------------------------------
void PhoenixServoSW::commit(u16 wMoveTime)
{
    mSGM.commit(wMoveTime);
}

//-----------------------------------------------------------------------------
// release
//-----------------------------------------------------------------------------
void PhoenixServoSW::release(void)
{
    for (u8 i = 0; i < CONFIG_NUM_LEGS * CONFIG_DOF_PER_LEG; i++) {
        mServoLegs[i].detach();
    }
    mBoolServosAttached = FALSE;
}
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

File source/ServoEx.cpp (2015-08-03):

/*
 ServoEx.cpp - Interrupt driven Servo library for Arduino using 16 bit timers- Version 2
 Copyright (c) 2009 Michael Margolis.  All right reserved.

 This version was extended by Kurt Eckhardt to allow for timed moves, including a group move where
 one or more servos are told to go a new end point and that they should take a specific time to
 get there.


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
 You should have received a copy of the GNU Lesser General Public
 License along with this library; if not, write to the Free Software
 Foundation, Inc., 51 Franklin St, Fifth Floor, Boston, MA  02110-1301  USA
 */

/*

   A servo is activated by creating an instance of the ServoEx class passing the desired pin to the attach() method.
  The Servos are pulsed in the background using the value most recently written using the write() method

  Note that analogWrite of PWM on pins associated with the timer are disabled when the first servo is attached.
  Timers are seized as needed in groups of 12 servos - 24 servos use two timers, 48 servos will use four.
  The sequence used to sieze timers is defined in timers.h

  The methods are:

   ServoEx - Class for manipulating servo motors connected to Arduino pins.

   attach(pin )  - Attaches a servo motor to an i/o pin.
   attach(pin, min, max  ) - Attaches to a pin setting min and max values in microseconds
   default min is 544, max is 2400

   write()     - Sets the servo angle in degrees.  (invalid angle that is valid as pulse in microseconds is treated as microseconds)
   writeMicroseconds() - Sets the servo pulse width in microseconds
   read()      - Gets the last written servo pulse width as an angle between 0 and 180.
   readMicroseconds()   - Gets the last written servo pulse width in microseconds. (was read_us() in first release)
   attached()  - Returns TRUE if there is a servo attached.
   detach()    - Stops an attached servos from pulsing its i/o pin.

   New methods:
	moving      - Returns TRUE if the servo is still moving to it's new location.
    move	     - Move the one servo to a new location...

	New Class ServoGroupMove - used to start a new group move.  There is one instance of this class
    	defined ServoGroupMove.

	The methods are:

    start         - Starts a group move.  The servos are not moved until the commit call
    commit	    - Commits the moves(write, writeMicroseconds) that happened since start

    moving	    - Returns a bitmask of the servos that are still moving.  The bits are in the order
                  the servos were created.
    wait	    - Waits for all of the servos defined in the mask are to their end points.

*/

#include <avr/interrupt.h>
#include <Arduino.h>

#include "ServoEx.h"

#define usToTicks(_us)    (( clockCyclesPerMicrosecond()* _us) / 8)     // converts microseconds to tick (assumes prescale of 8)  // 12 Aug 2009
#define ticksToUs(_ticks) (( (unsigned)_ticks * 8)/ clockCyclesPerMicrosecond() ) // converts from ticks back to microseconds



#define TRIM_DURATION       2                               // compensation ticks to trim adjust for digitalWrite delays // 12 August 2009

//#define NBR_TIMERS        (MAX_SERVOS / SERVOS_PER_TIMER)

static servo_t servos[MAX_SERVOS];                          // static array of servo structures
static volatile int8_t Channel[_Nbr_16timers ];             // counter for the servo being pulsed for each timer (or -1 if refresh interval)

uint8_t ServoCount = 0;                                     // the total number of attached servos

// Group move variables
uint8_t GroupMoveActiveCnt = 0;                                // Do we have a group move active at this time?
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

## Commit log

2015-07-17 Initial upload
    [Hexa.sdf]
2015-07-28 Add SW button
2015-08-05 Fix button checking bug
2015-08-10 doc and ref removed from github
    [Hexa.sdf]
2015-08-12 bug fix battery level
    [PhoenixCore.cpp]
2015-08-13 code rework
    sound routine,
    battery level
    [PhoenixCore.cpp, config.h, utils.cpp]
2015-09-21 battery volt and servo test
2015-11-09 servo command check
2015-11-11 shared uart between usc and btcon
2015-11-20 set tx rx buffer to 256 for arduino mega
2015-11-20 battery level fix
2015-11-30 stl folder added
    [BattConnHolder_V2.stl, femur_v2.stl, head_back.stl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]

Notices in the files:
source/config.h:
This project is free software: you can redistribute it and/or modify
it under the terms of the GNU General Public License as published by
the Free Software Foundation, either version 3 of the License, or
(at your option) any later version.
